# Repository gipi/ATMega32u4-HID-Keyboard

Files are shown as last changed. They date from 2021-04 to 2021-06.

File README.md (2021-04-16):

## ATMega32u4 HID Keyboard

### Board Project 2019 - Krishna Mani

This is software for ATMega32u4 or compatible AVR hardware USB chips that
implements a standard-complying HID keyboard using only AVR-LIBC.

I used these for reference when coding:

1. https://www.avrfreaks.net/forum/usb-initialization-problem
2. https://www.pjrc.com/teensy/usb_keyboard.html
3. https://www.usb.org/sites/default/files/documents/hid1_11.pdf
4. https://www.avrfreaks.net/forum/help-properly-initializing-usb-hardware-atmega32u4
5. https://www.beyondlogic.org/usbnutshell/usb1.shtml
6. http://ww1.microchip.com/downloads/en/devicedoc/atmel-7766-8-bit-avr-atmega16u4-32u4_datasheet.pdf
7. https://github.com/arduino/ArduinoCore-avr/blob/master/cores/arduino/USBCore.cpp
8. http://sdphca.ucsd.edu/lab_equip_manuals/usb_20.pdf

Finished Board:

Finished Board

### Hardware

##### Microcontroller

The ATMega32u4 controls the scanning matrix and the USB interface. I chose it
because of its hardware USB interface and because it has enough I/O pins to
support the whole keyboard without needing any multiplexing. It also has enough
flash and SRAM for storing layouts. The 32u4 on the keyboard runs at 16mHz from
an external crystal oscillator with 22pF load capacitors. It is powered directly
from the USB lines with filtering capacitors.

##### PCBs

Initially, I needed to test the main microcontroller circuit of the keyboard to
ensure that it worked and that the USB worked, because I had developed on an
Arduino Leonardo. (boards/ATMegaTestingBoard.brd)

##### ATMega32u4 Circuit

The portion of the board for the ATMega32u4 is fairly standard for this chip and
is similar to the Arduino Leonardo, excluding the power regulators. It consists
of the chip, the oscillator and load caps, the power and layer leds, the reset
switch, the USB connector and data resistors, the ICSP pins, and the filtering
    caps on the underside of the board.

Top / Bottom (boards/Keyboard.brd):

32u4 Top

32u4 Bottom

The rest of the board is the scanning matrix. The rows and columns use up the
majority of the I/O on the chip.  The matrix is standard for a keyboard - one
pin of each switch in a column is connected through a diode to every other one
in the column. Then, the remaining pin in each switch is common with the row. I
used through hole diodes because they are much easier to solder. The switches
are standard mechanical keyboard switches, and the footprints are from here:
https://github.com/mknyszek/gateron-eagle To read the matrix, the row pins are
pulled high through internal pull-up resistors. One column at a time is set low,
so that a pressed key would pull the row pin low, signaling a key press at the
current row and column index.

Top / Bottom matrix (boards/Keyboard.brd):

Matrix Top

Matrix Bottom

##### Board Assembly

Assembling the board was straightforward except for the SMD components,
specifically the TQFP ATMega32u4. It is really easy to bridge several pads very
quickly, and completely ruin the chip. I soldered these by holding them in place
and tacking down the corners so the chip didn’t move. I used a lot of flux, then
with very little solder dragged the iron across the pins. The USB connector is
also really difficult, I soldered the anchor pins and then the pins. It is
really easy to bridge the pins with the ground enclosure. Using super glue after
ensures that the connector doesn’t snap off when you unplug the cable.

### Code

To compile you need ``cmake``

```
$ mkdir build && cd build
$ cmake -DCMAKE_TOOLCHAIN_FILE=/path/to/cmake-avr/generic-gcc-avr.cmake ..
$ make
```

##### USB

First, the USB controller of the 32u4 is initialized. This is handled in the
function `usb_init()`. The PLL (Phase Locked Loop) is initialized, taking the
external clock as input. It runs at 48mHz and acts as the USB clock. After the
USB controller is initialized, the control endpoint is set up and will receive
setup packets from the host. The setup packets, handled in the ISR
`USB_gen_vect`, elicit responses from the keyboard based on the values of
bmRequestType and bRequest, which determine the type of request. After the host
has requested and received the USB descriptors, and the keyboard has correctly
responded to HID-specific requests, the host can enumerate the device and use it
as an input device.

The key repeat feature of modern keyboards is handled separately from the
standard functions `usb_send()` and `usb_send_keypress()`. If a key is held down
for some period of time, it should be repeated until it is released. This is
    taken care of in the ISR `USB_gen_vect`, specifically when the SOFE (start
    of frame) bit is set. This interrupt triggers at 1kHz, which is how often
    the host sends start of frame packets. If no keypresses have been generated
    since the period time, which is kept track of with keyboard_idle_value and
    current_idle, the entire HID report is resent to facilitate key repeat. The
    period of time the device should wait before resending the report is set
    from the wValue in the HID request SET_IDLE.

##### Matrix Software

The scanning matrix of the keyboard uses the current sourcing and internal
pullups of the I/O ports on the 32u4. Because of the orientation of the diodes,
the columns of the keyboard are set low when they are going to be read. The rows
are always pulled up, meaning that if a key is pressed, it will be pulled low
because the switch is connecting the row and columns. The matrix scanning is
repeated quickly, and changes in key state are recorded in the six-byte USB HID
report. The report is six bytes to support six concurrent key presses. The
keyboard dynamically assigns and removes keys from the report to support
6-key-rollover, and it also resets the reports on layout layer shifts to prevent
strange glitches. The meta and special keys like CTRL, ALT, and SHIFT have their
own byte apart from the report, where each bit represents a different key. This
is according to the USB HID Spec.

The rows and columns of the recorded keypresses are translated into actual
keycodes from the specified layout in `layout.h`. The layout is written from the
standard HID keycodes in `keys.h`. Because the keyboard does not have enough
physical keys to support all the letters, function, and number keys, some keys
are macros that change the mappings of all the keys. These keys are handled
separately and do not generate keypress events on their own. Rather, they update
the current layer that the scanning matrix is reporting keypresses from to
change the keycodes.

### Improvements

1. Changing the routing on PORTD to make it iterable, making the code more readable and cleaner.
2. Using USB-C instead of micro b, meaning that you would not need a dongle for use with newer macs. This would, however, make it much more difficult to solder and the PCB more complicated, since the USB-C connectors have 24 pins.
3. Using the BGA package for the ATMega32u4 so that it could fit in between switches on the underside of the board, meaning that the PCB would only have to be as big as to fit the switches. This would make it more compact.
4. Using symmetrical keycaps so that the keycaps aren’t skewed when using keyboard layouts other than QWERTY.
5. Adding support for a dedicated FN key endpoint and Caps lock and num lock; currently you have to remap function to media keys with a third party tool for the media keys on the keyboard to work on touch bar macs.
6. Move the ICSP connector down, right now you have to bend the power LED up for the connector to make contact with the headers.
7. Route the third layer led to a different I/O port, right now only two of the three LEDs work.

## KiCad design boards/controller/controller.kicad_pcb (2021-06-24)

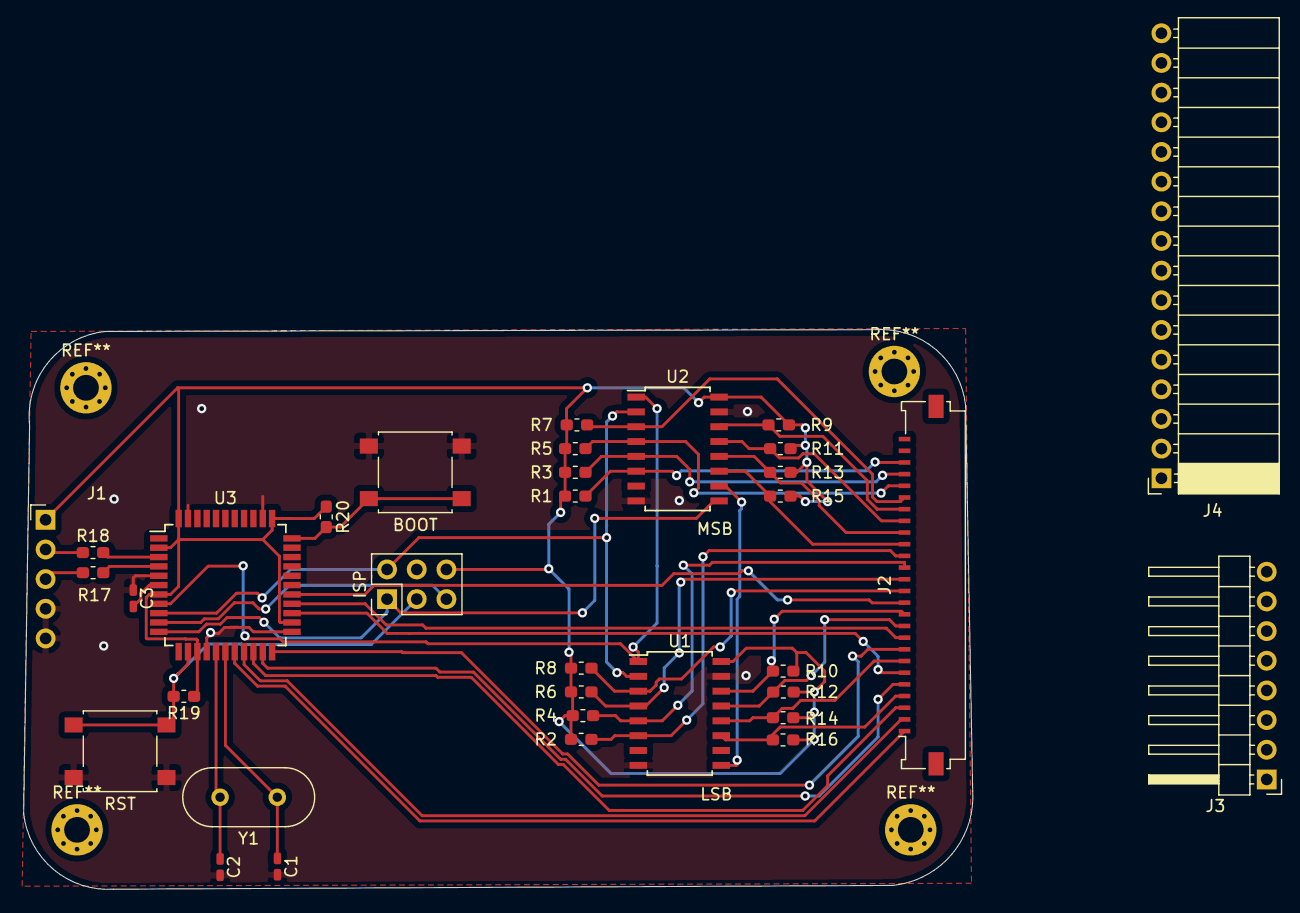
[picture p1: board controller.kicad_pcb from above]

Board: 2 copper layers, 81.3 x 47.9 mm, 34 parts (0 on the bottom side), 40 nets.

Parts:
BOOT: SW_Push; SW_SPST_B3S-1000
C1, C2: C; C_0402_handSoldering
C3: 1uF; C_0402_handSoldering
ISP: Conn_02x03_Counter_Clockwise_MountingPin; PinHeader_2x03_P2.54mm_Vertical
J1: USB_A; PinHeader_1x05_P2.54mm_Horizontal
J2: Conn_01x26; Molex_200528-0260_1x26-1MP_P1.00mm_Horizontal
J3: Conn_01x08; PinHeader_1x08_P2.54mm_Horizontal
J4: Conn_01x16; PinSocket_1x16_P2.54mm_Horizontal
R1, R2, R3, R4, R5, R6, R7, R8, R9, R10, R11, R12, R13, R14, R15, R16, R17, R18, R19, R20: R; R_0603_1608Metric_Pad1.05x0.95mm_HandSolder
RST: SW_Push; SW_SPST_B3S-1000
U1, U2: 74LS165; SOIC-16W_5.3x10.2mm_P1.27mm
U3: ATmega32U4-AU; TQFP-44_10x10mm_P0.8mm
Y1: Crystal; Crystal_HC18-U_Vertical

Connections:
/I0: J2.1, J3.1, U3.18
/I1: J2.2, J3.2, U3.19
/I2: J2.3, J3.3, U3.20
/I3: J2.5, J3.4, U3.21
/I4: J2.6, J3.5, U3.25
/I5: J2.8, J3.6, U3.22
/I6: J2.9, J3.7, U3.26
/I7: J2.12, J3.8, U3.27
/O0: J2.4, J4.1, R16.2, U1.11
/O1: J2.7, J4.2, R14.2, U1.12
/O2: J2.10, J4.3, R12.2, U1.13
/O3: J2.11, J4.4, R10.2, U1.14
/O4: J2.13, J4.5, R8.2, U1.3
/O5: J2.14, J4.6, R6.2, U1.4
/O6: J2.15, J4.7, R4.2, U1.5
/O7: J2.16, J4.8, R2.2, U1.6
/O8: J2.17, J4.9, R15.2, U2.11
/O9: J2.18, J4.10, R13.2, U2.12
/O10: J2.19, J4.11, R11.2, U2.13
/O11: J2.20, J4.12, R9.2, U2.14
/O12: J2.21, J4.13, R7.2, U2.3
/O13: J2.22, J4.14, R5.2, U2.4
/O14: J2.23, J4.15, R3.2, U2.5
/O15: J2.24, J4.16, R1.2, U2.6
BOOT: BOOT.1, R20.2, U3.33
GND: BOOT.2, C1.2, C2.2, C3.1, ISP.4, J1.4, J1.5, RST.1, U1.8, U1.15, U2.8, U2.15, U3.5, U3.15, U3.23, U3.35, U3.43
MISO: ISP.1, U2.9, U3.11
MOSI: ISP.5, U3.10
unnamed: C1.1, U3.17, Y1.1
unnamed: C2.1, U3.16, Y1.2
unnamed: C3.2, U3.6
unnamed: J1.2, R18.1
unnamed: J1.3, R17.1
unnamed: R17.2, U3.4
unnamed: R18.2, U3.3
unnamed: U1.9, U2.10
RESET: ISP.3, R19.2, RST.2, U3.13
SCK: ISP.2, U1.2, U2.2, U3.9
SS: U1.1, U2.1, U3.8
VCC: ISP.6, J1.1, R1.1, R2.1, R3.1, R4.1, R5.1, R6.1, R7.1, R8.1, R9.1, R10.1, R11.1, R12.1, R13.1, R14.1, R15.1, R16.1, R19.1, R20.1, U1.16, U2.16, U3.2, U3.7, U3.14, U3.24, U3.34, U3.44

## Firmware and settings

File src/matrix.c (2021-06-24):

/*
 * matrix.c
 */
#include "matrix.h"
#include "layout.h"
#include "usb.h"
#include <avr/interrupt.h>
#include <avr/io.h>
#include <avr/pgmspace.h>
#include <stdbool.h>
#include <util/delay.h>

#define pin_output(x,y) DDR##x |= _BV(P##x##y);
#define pin_high(x,y) PORT##x |= _BV(P##x##y)
#define pin_low(x,y) PORT##x &= ~_BV(P##x##y)

#define port_output(port) DDR##port = 0xff
#define port_high(port) PORT##port = 0xff

inline void input_low(uint8_t pin) {
    PORTD &= ~_BV(pin);
}

inline void input_high(uint8_t pin) {
    PORTD |= _BV(pin);
}

#define SS_high() pin_high(B,0)
#define SS_low() pin_low(B,0)

#define DDR_SPI DDRB
#define DD_MOSI PB2
#define DD_MISO PB3
#define DD_SCK  PB1
#define DD_SS   PB0

void SPI_master_init() {
    /* Set MOSI, SS and SCK output, all others input */
    DDR_SPI = (1 << DD_MOSI) | (1 << DD_SCK) | (1 << DD_SS);
    /* Enable SPI, Master, set clock rate fck/16 */
    SPCR = (1 << SPE) | (1 << MSTR) | (1 << SPR0); // | (1 << DORD);
}


/* while we transmit we also receive */
uint8_t SPI_masterTransmit(char cData)
{
    /* Start transmission */
    SPDR = cData;
    /* Wait for transmission complete */
    while(!(SPSR & (1 << SPIF)))
        ;

    return SPDR;
}

int layout_num = 0;
bool has_unsent_packets = false;

bool state_layer[NUM_ROWS][NUM_COLS] = {
    {1, 1, 1, 1, 1, 1, 1, 1, 1, 1, 1, 1, 1, 1, 1, 1},
    {1, 1, 1, 1, 1, 1, 1, 1, 1, 1, 1, 1, 1, 1, 1, 1},
    {1, 1, 1, 1, 1, 1, 1, 1, 1, 1, 1, 1, 1, 1, 1, 1},
    {1, 1, 1, 1, 1, 1, 1, 1, 1, 1, 1, 1, 1, 1, 1, 1},
    {1, 1, 1, 1, 1, 1, 1, 1, 1, 1, 1, 1, 1, 1, 1, 1},
    {1, 1, 1, 1, 1, 1, 1, 1, 1, 1, 1, 1, 1, 1, 1, 1},
    {1, 1, 1, 1, 1, 1, 1, 1, 1, 1, 1, 1, 1, 1, 1, 1},
    {1, 1, 1, 1, 1, 1, 1, 1, 1, 1, 1, 1, 1, 1, 1, 1}};  // Key States to do state changes

void matrix_init() {
  SPI_master_init();
  SS_low(); // when low the shift registers are in LOAD mode
  port_output(D);
  port_high(D);

  TCCR0B |= (1 << CS00) | (1 << CS02); // Set up the 1024 prescaler on timer 0
  TCCR0A = (1 << WGM01); // Set the timer to compare mode
  OCR0A = 255; // Set the compare value to max for a lower frequency
  TIMSK0 = (1 << OCIE0A); // Enable timer compare interrupts
}

void do_layer_led() { PORTC = layout_num << 6; }

/*
 * Set the input pin to low.
 */
void enable_input(unsigned int j) {
    input_low(j);
}

void disable_input(unsigned int j) {
    input_high(j);
}
/*
 * Use the state of the button and identify the possible situation.
 */
void do_handle_keypress(bool state, unsigned int i, unsigned int j) {

    if (state != state_layer[i][j]) { // Is the value in the state array different from the value read from the key?
        if (!state) {  // Low to High (Key Down)

            uint16_t key = layout[layout_num][i][j];
            if (key & KEY_MOD_MACRO) { // Is this a macro key, in which case we have to set the appropriate value in the modifier bit
                key &= ~(KEY_MOD_MACRO);
                keyboard_modifier |= key;

            } else if (key & KEY_LS_MACRO) { // Is this a layer shift macro, in which case we have to change the layer number
                key &= ~(KEY_LS_MACRO);
                if ((layout_num | key) <= (NUM_LAYERS - 1)) { // Make sure we're not shifting to a layer that doesn't exist
                    layout_num |= key;
                    do_layer_led(); // Set the layer LEDs
                    for (int k = 0; k < 6; k++) {
                        keyboard_pressed_keys[k] = 0; // We have to clear the report after shifting layers because of conflicts from key-ups and key-downs on different layers
                    }
                }
            } else { // This is just a normal keypress, record it in the first available slot in the HID report 
                for (int k = 0; k < 6; k++) {
                    if (keyboard_pressed_keys[k] == 0) { // '0' is the code for no key press
                        keyboard_pressed_keys[k] = key; 
                        break;
                    }
                }
            }
        } else { // Handle key up events
            uint16_t key = layout[layout_num][i][j];
            if (key & KEY_MOD_MACRO) { // Is this a macro key, we have to remove the macro bit from the modifier byte to signify a key up
                key &= ~(KEY_MOD_MACRO);
                keyboard_modifier &= ~(key);

            } else if (key & KEY_LS_MACRO) { // Is this a layer shift key, we have to remove the bit from layout_num to switch back to the previous layer
                key &= ~(KEY_LS_MACRO);
                for (int k = 0; k < 6; k++) {
                    keyboard_pressed_keys[k] = 0; // Clear the HID report
                }
                layout_num &= ~(key);
                do_layer_led();
            } else {
                for (int k = 0; k < 6; k++) { // Normal key up event, find the key in the HID report and remove it
                    if (keyboard_pressed_keys[k] == key) {
                        keyboard_pressed_keys[k] = 0;
                    }
                }
            }
        }
        state_layer[i][j] = state; // Record the changed state in the array to register future state changes
        has_unsent_packets = true; // Let the timer interrupt know that we've got some packets to be sent
    }

}

/*
 * The matrix scan loops over the PORTB pins for the rows and read via SPI the
 * pins having asserted low signal.
 *
 */
void do_matrix_scan() {
    for (int row = 0; row < NUM_ROWS; row++) {
            enable_input(row);

            SS_high(); // enable shifting

            uint8_t c0 = SPI_masterTransmit(0x5a);
            uint8_t c1 = SPI_masterTransmit(0x5a);

            SS_low(); // re-enable loading
            disable_input(row);

            uint16_t c = c0 << 8 | c1;

            for (unsigned int column = 0; column < NUM_COLS; column++) {
                bool state = (c >> column) & 1;

                do_handle_keypress(state, row, column);
            }
    }
#if 0
            for (int k = 0; k < 6; k++) {
                if (keyboard_pressed_keys[k] == 0) { // '0' is the code for no key press
                    keyboard_pressed_keys[k] = KEY_A; 
                    break;
                }
            }
    has_unsent_packets = true; // Let the timer interrupt know that we've got some packets to be sent
#endif
}

ISR(TIMER0_COMPA_vect) { // The USB packets are sent on a timer interrupt because OSX was showing strange USB keypress rejection errors due to high USB packet frequency
  if (has_unsent_packets) {
    usb_send();
    has_unsent_packets = false;
  }
}
